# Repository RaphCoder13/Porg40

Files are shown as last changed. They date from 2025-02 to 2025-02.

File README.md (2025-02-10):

# Porg40
A 40 keys low-profile split keyboard, handwired and 3d printed.

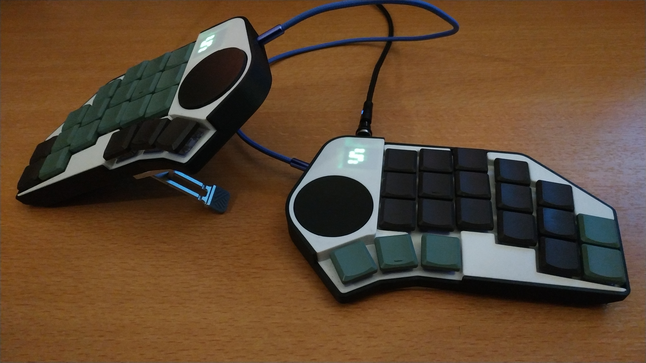
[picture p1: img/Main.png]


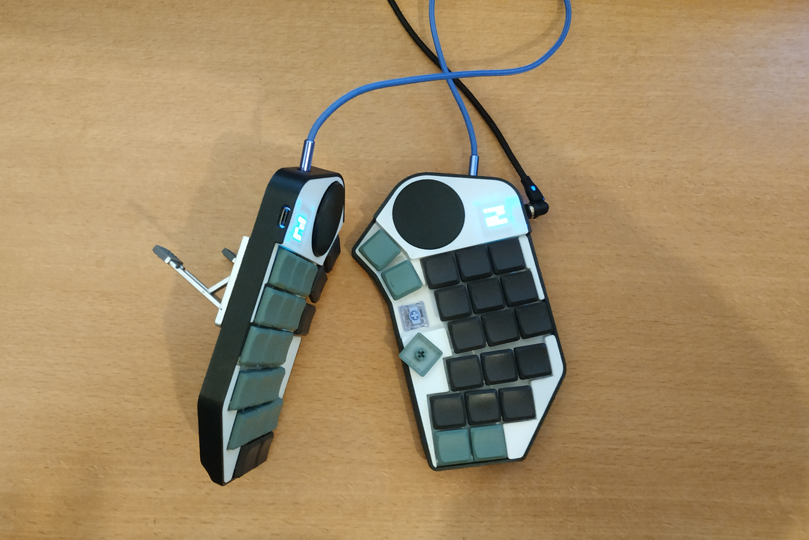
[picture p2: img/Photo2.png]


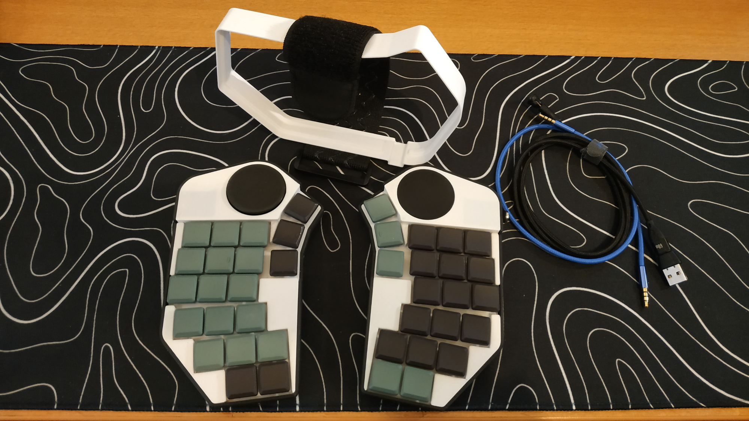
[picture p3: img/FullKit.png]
Full kit


## Features

- Low profile design with GS-33 switches and Tai-Hao low-profile keycaps
- Led matrix layer display
- 40mm Cirque Trackpad (right side)
- 4-way switch (left side)

## Supplies

- 2x Waveshare RP2040 Matrix
- 40x Nuphy Wisteria switches
- 40x Tai-Hao MX low-profile keycaps
- 40mm Cirque Trackpad
- FPC adaptor and cable for trackpad (12 pins)
- 5-way switch
- 44x ln4148 diodes
- TRRS connectors and cable
- M2.5 heat inserts
- M2.5 standoffs
- 1mm enamelled copper wire
- Folding legs for phone

## Build notes

### Printing

All the files are designed for the right side, don't forget to mirror them when printing the left side.
The plates are different wheither you are using the trackpad or the 5-way switch.

#### Side with Trackpad
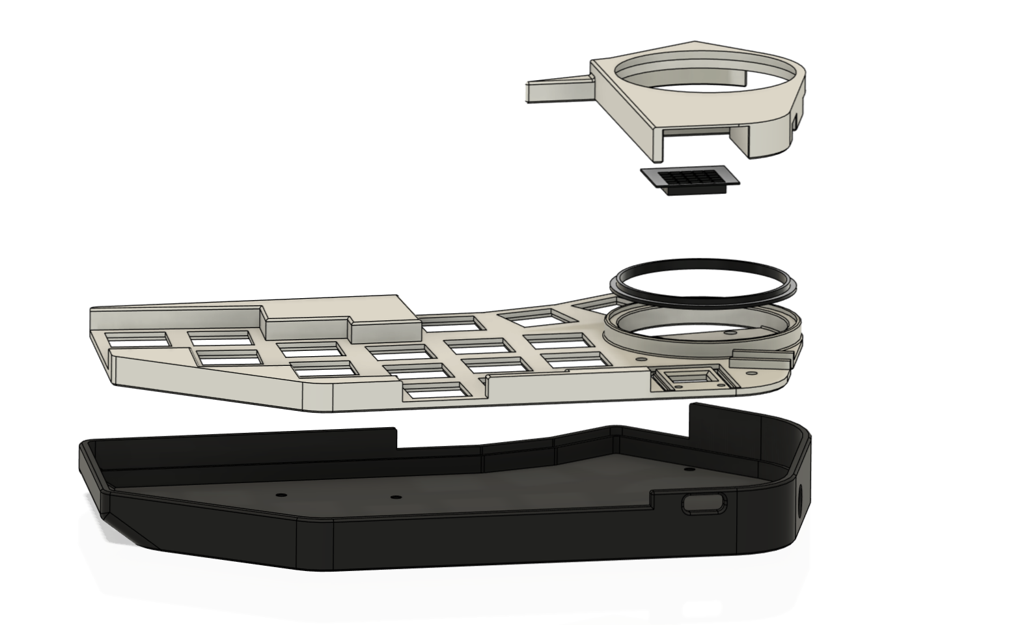
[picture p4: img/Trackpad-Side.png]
Trackpad plate

From top to bottom
- Cover
- Led grid
- Trackpad support
- Plate
- case

#### Side with 5-way switch

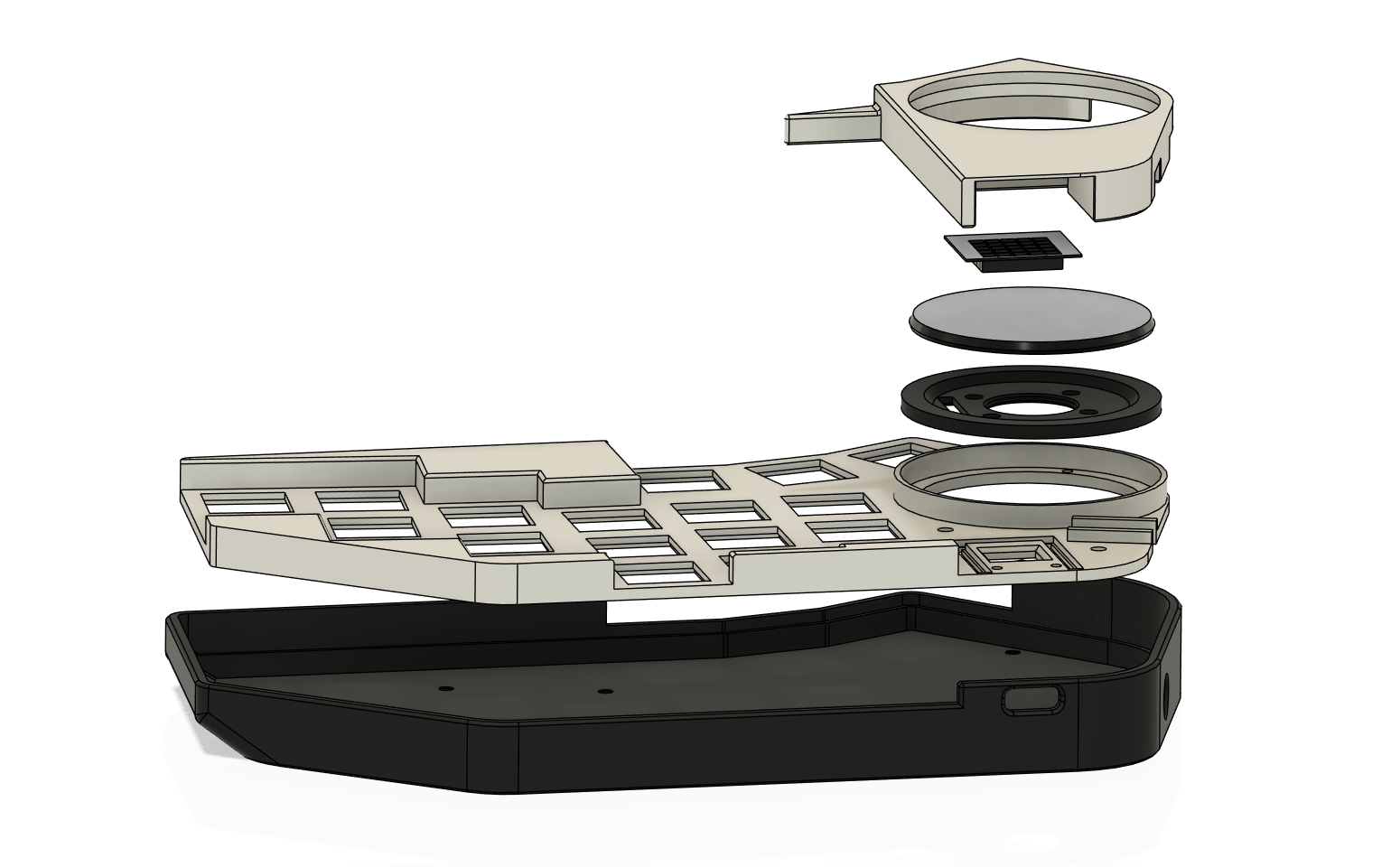
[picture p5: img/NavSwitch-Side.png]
5-way plate

From top to bottom:
- Cover
- Led grid
- DPad - NavSwitch keycap
- NavSwitch support
- Plate
- case|

### Assembly

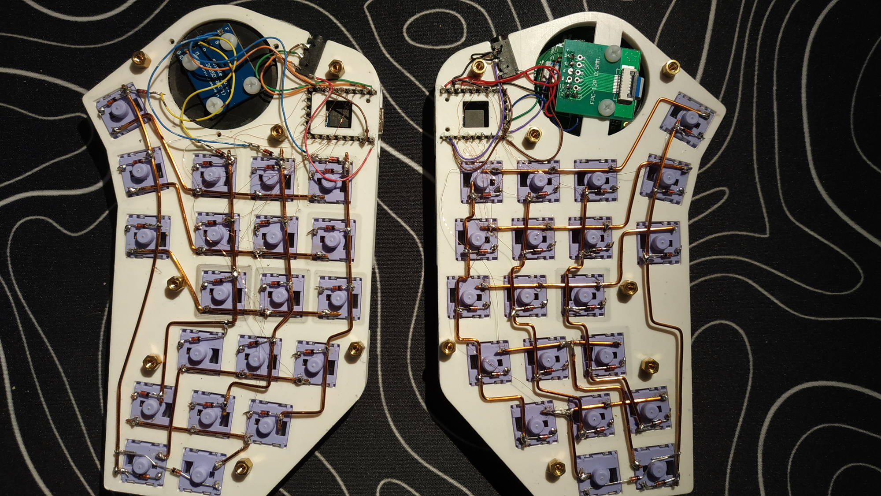
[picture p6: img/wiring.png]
Wiring

The RP2040 is socketed with Mill-Max round pin header glued on the plate.

I used 1mm enamelled copper wire for the rows and columns and very thin enamel wire to connect to the pin header, I wrap them around the pin header and solder them.

The trackpad is connected to a SMT adaptor with a 12 pin FPC cable.

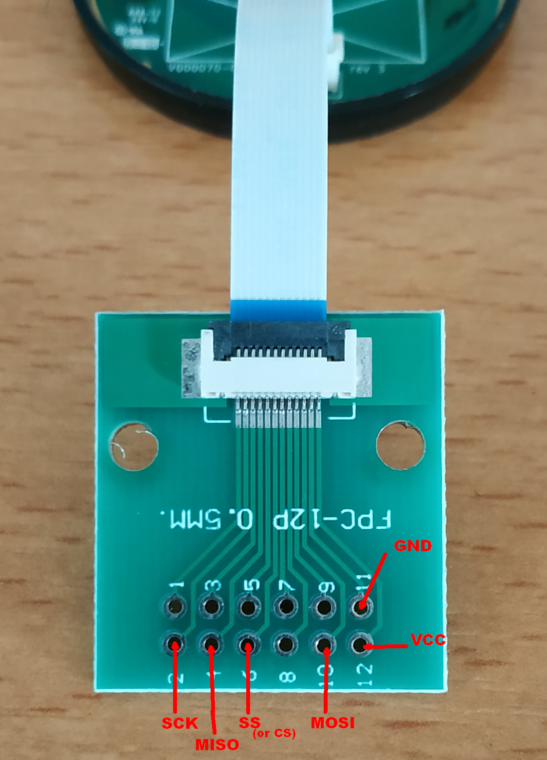
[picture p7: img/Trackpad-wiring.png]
Trackpad wiring

Keep in mind that the order can be reversed if you use a forward or reverse direction FPC cable.

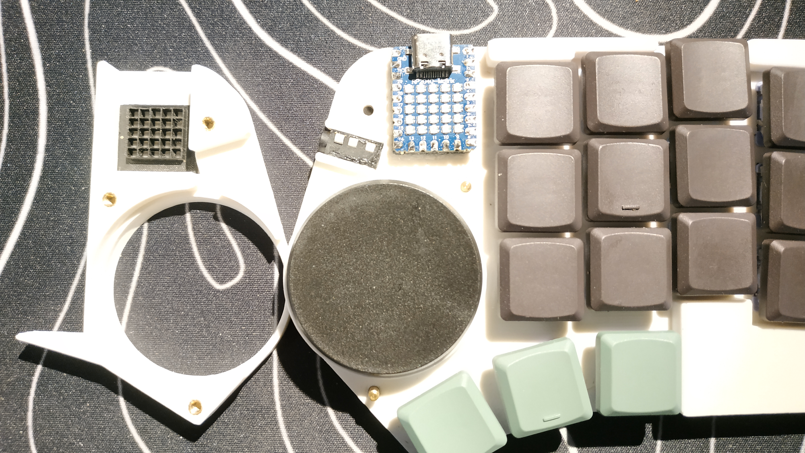
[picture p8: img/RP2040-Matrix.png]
RP2040 placement


The TRRS connector is glued to the plate.
After finding the good orientation, the NavSwitch support is glued to the plate.

The led grid is glued to the cover, it must be aligned with the led matrix on the RP2040.

Place the heat inserts in the cover and the plate, the standoffs maintain the cover on the plate and the plate on the case.

### Transport

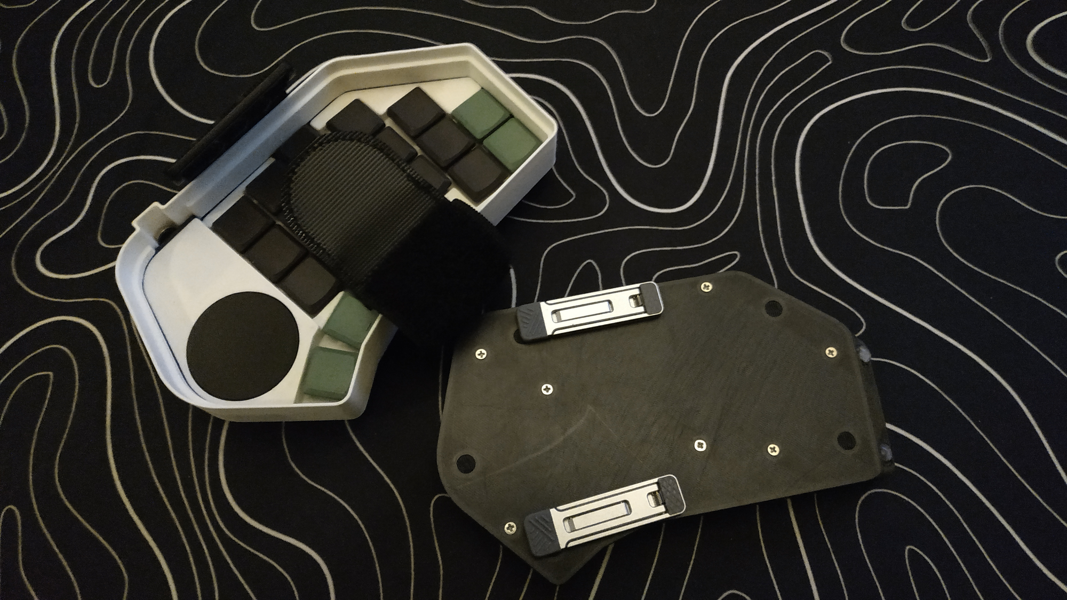
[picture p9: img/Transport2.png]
Transport

I used a 3D printed case to transport the keyboard, bento style. The case take into account the usb-c magnetic connector staying in place on the right side. An elastic velcro strap is used to hold everything together.

## Credits and inspiration
- [Joe Scotto's videos](https://www.youtube.com/@joe_scotto) on hand wiring.
- [Totem](https://github.com/GEIGEIGEIST/TOTEM) keyboard by GEIGEIGEIST.
- Many other things I saw on [kbd.news](https://kbd.news) and reddit.

## License

This work is licensed under a <a rel="license" href="http://creativecommons.org/licenses/by-nc-sa/4.0/">Creative Commons Attribution-NonCommercial-ShareAlike 4.0 International License</a>

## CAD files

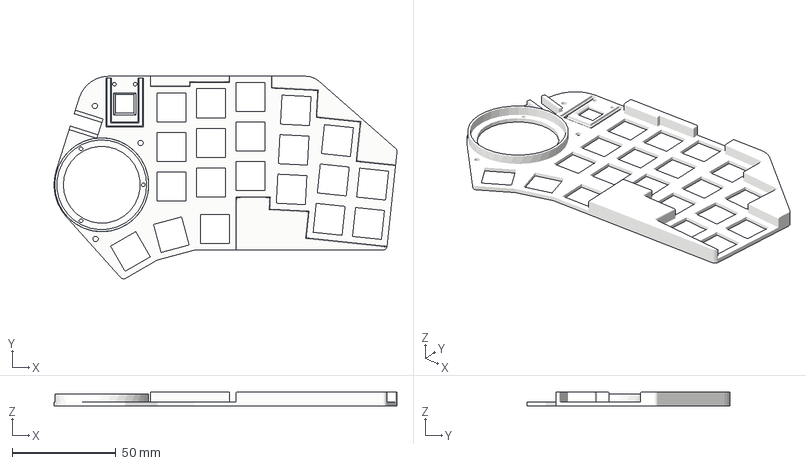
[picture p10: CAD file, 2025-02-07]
models/Plate for NavSwitch.3mf
165.1 x 97.6 x 6.95 mm

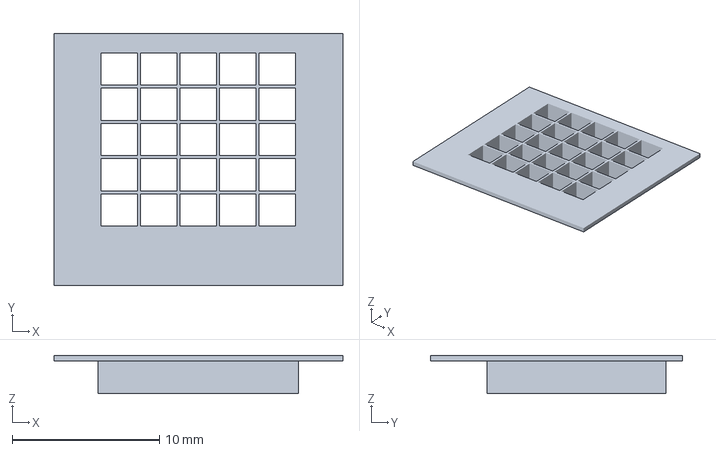
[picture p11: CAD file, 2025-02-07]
models/Led-grid.3mf
19.6 x 17.1 x 2.60 mm

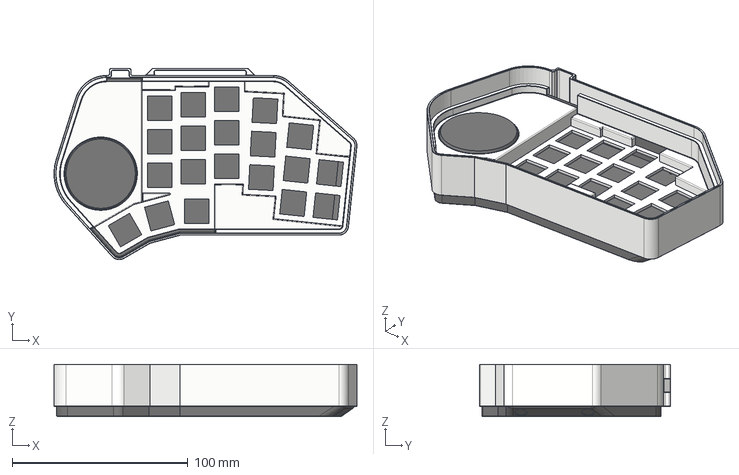
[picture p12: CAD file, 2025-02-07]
models/Porg-MX v102.iges
172.3 x 108.8 x 29.7 mm

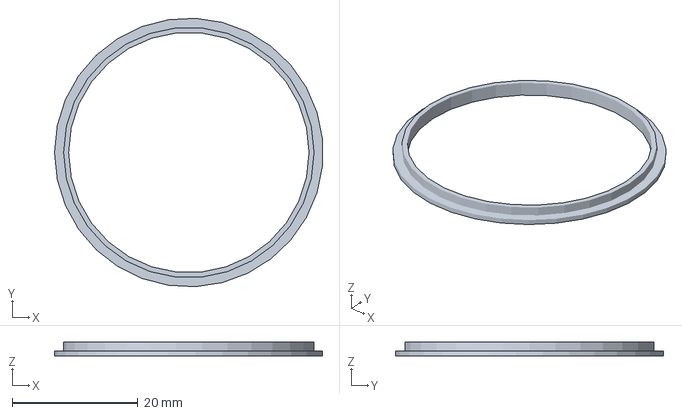
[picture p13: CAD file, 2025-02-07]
models/Trackpad-Support.3mf
42.7 x 42.7 x 2.20 mm

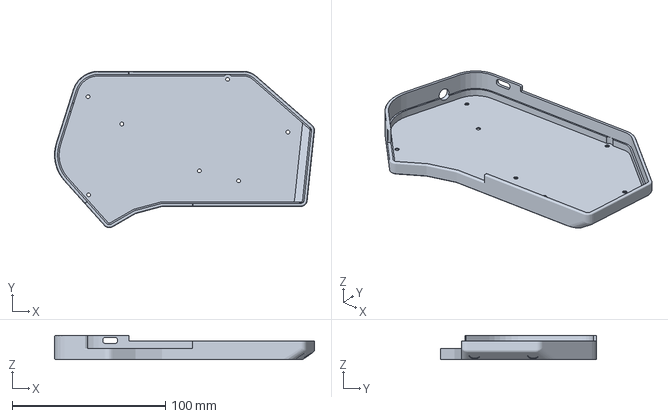
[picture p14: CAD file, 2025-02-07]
models/Case.3mf
169.5 x 102.0 x 15.7 mm

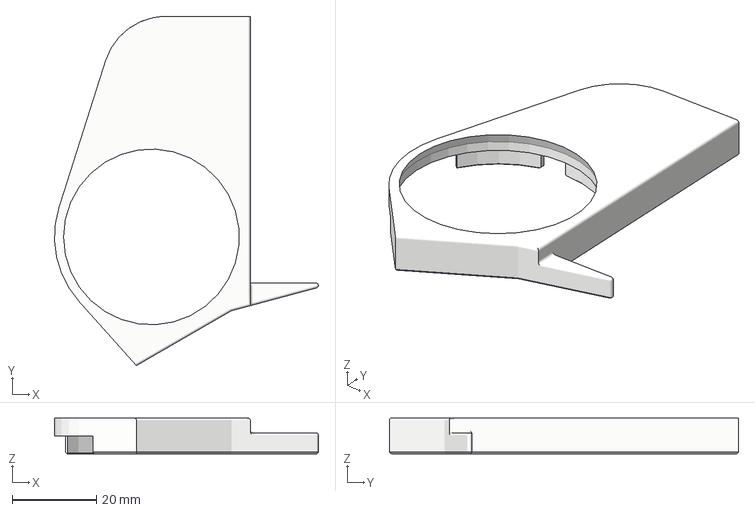
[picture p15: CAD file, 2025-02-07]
models/Cover.3mf
62.6 x 82.8 x 8.50 mm

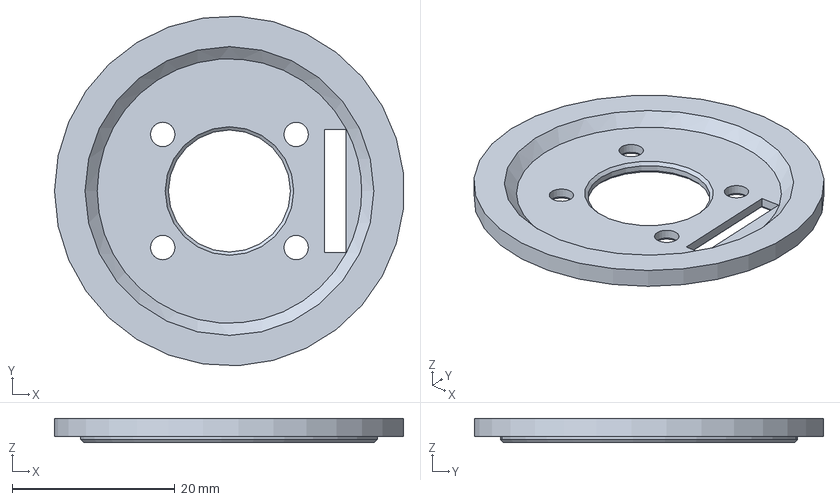
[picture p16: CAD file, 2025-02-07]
models/NavSwitch-Support.3mf
42.9 x 42.9 x 3.00 mm

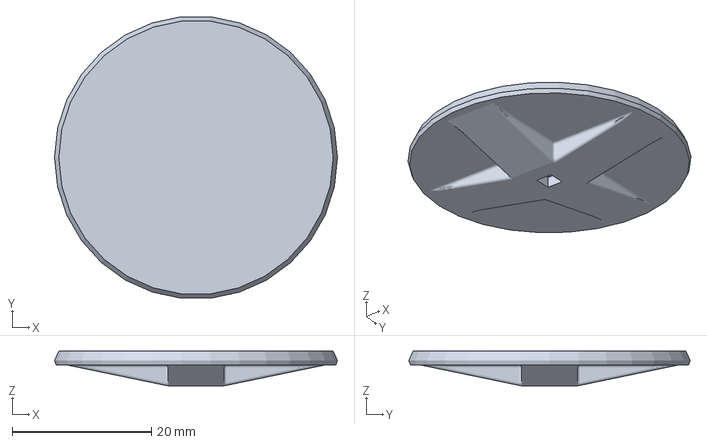
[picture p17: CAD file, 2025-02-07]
models/DPad - NavSwitch keycap.3mf
40.6 x 40.4 x 5.00 mm

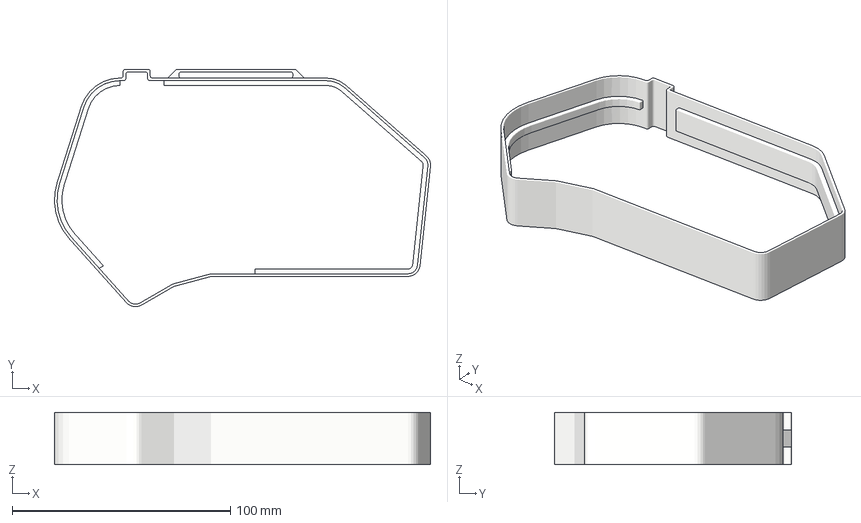
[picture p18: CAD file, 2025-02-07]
models/Transport-Case.3mf
172.3 x 108.8 x 24.0 mm

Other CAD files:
models/Plate for Trackpad.3mf
